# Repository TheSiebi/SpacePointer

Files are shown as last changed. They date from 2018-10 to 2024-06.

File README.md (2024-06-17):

# Space Pointer
 

A device using a Raspberry Pi and an Arduino Uno which can point at the position of the sun, moon, planets and galaxies.
Users can choose whether they want to visualize the current position, a specific timestamp or a simulation of the trajectory. Parts are self-designed and 3D-printed.

## Setup
 
 

Required parts:
- 1x Raspberry Pi (I used 3B)
- 1x Arduino (I used Uno Rev 3)
- 2x NEMA 17 Steppers
- 1x LCD (+ Keypad)
- 1x Laser 303 (or any other Laser, just modify Laser_Bracket.stl)
- 1x GPS Module
- 1x Slip Ring (I used Adafruit 22mm 12 cables)
- 2x Bearings Outer 16mm Inner 5mm

and some screws, batteries and cables.

## Demo
YouTube Demo (https://www.youtube.com/watch?v=DYivI0u8cRY)

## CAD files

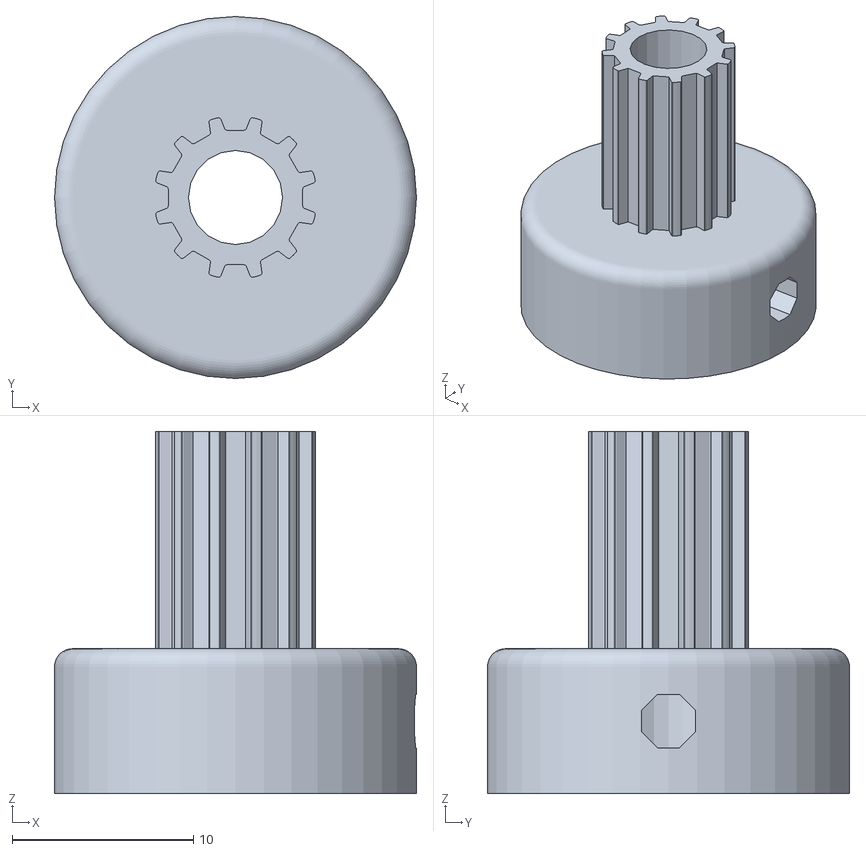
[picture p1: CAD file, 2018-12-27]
3d-parts/Pulley_12.stl
20.0 x 20.0 x 20.0

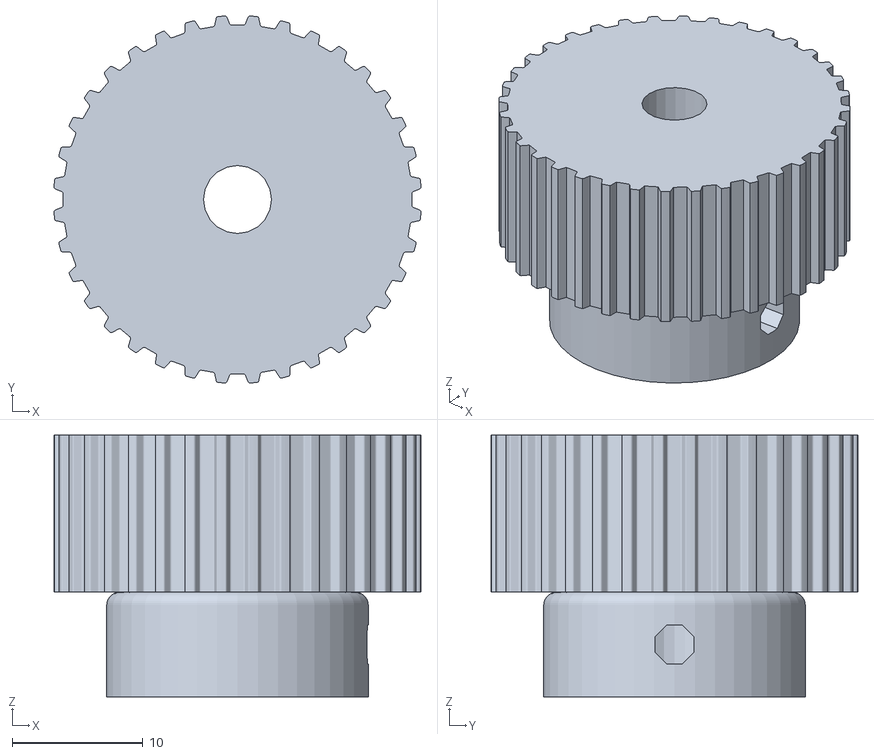
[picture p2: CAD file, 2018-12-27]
3d-parts/Pulley_36.stl
28.1 x 28.1 x 20.0

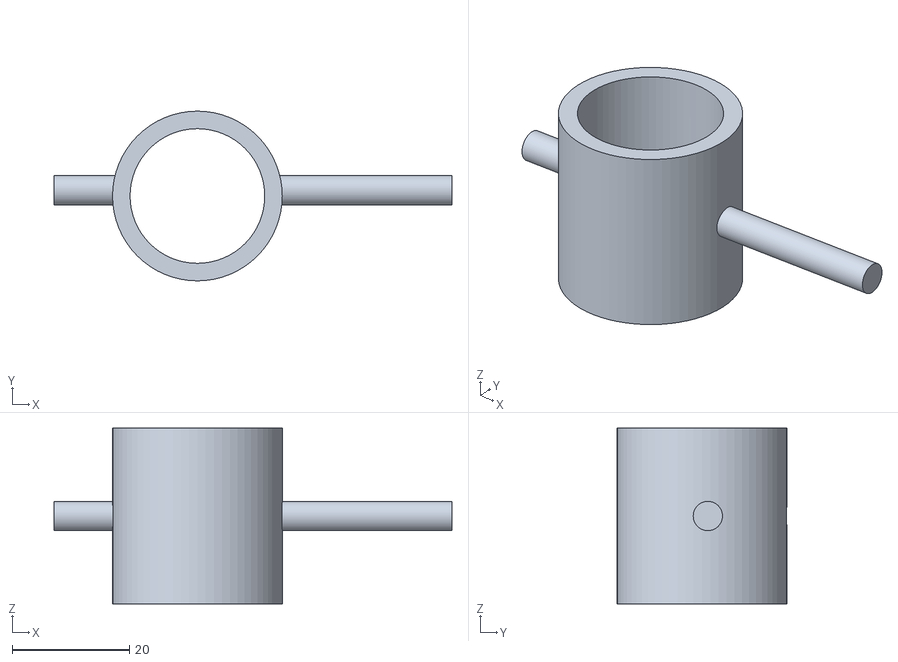
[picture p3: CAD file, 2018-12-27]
3d-parts/Laser_Bracket.stl
68.0 x 29.0 x 30.0

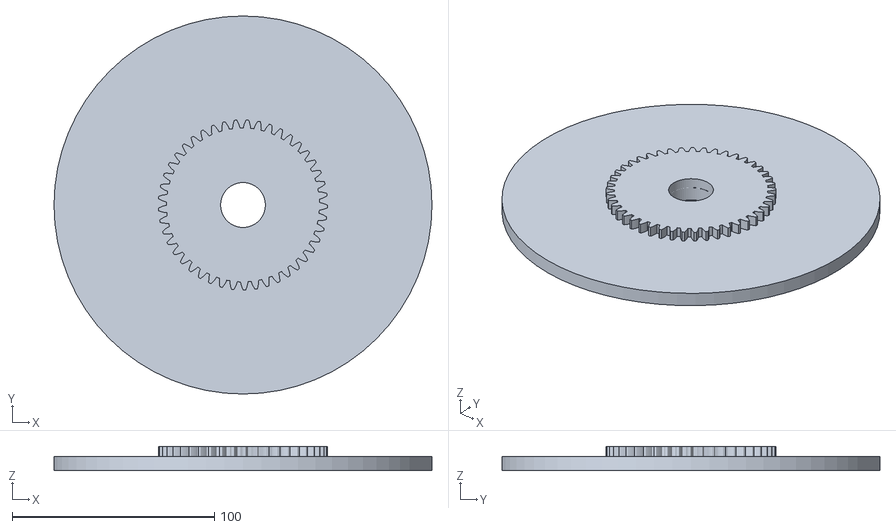
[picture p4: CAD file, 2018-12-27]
3d-parts/Lid.stl
187.0 x 187.0 x 12.1

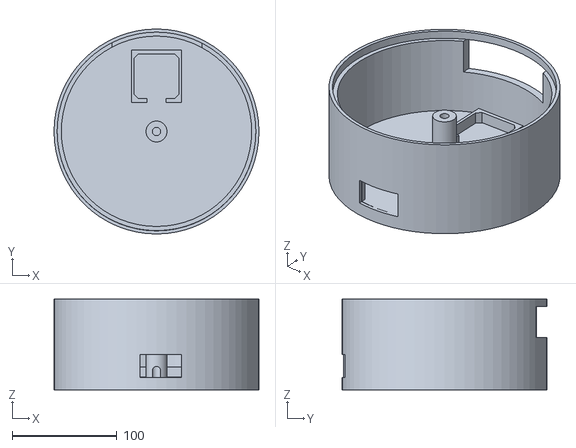
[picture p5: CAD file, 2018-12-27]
3d-parts/Casing.stl
196.0 x 196.0 x 87.0

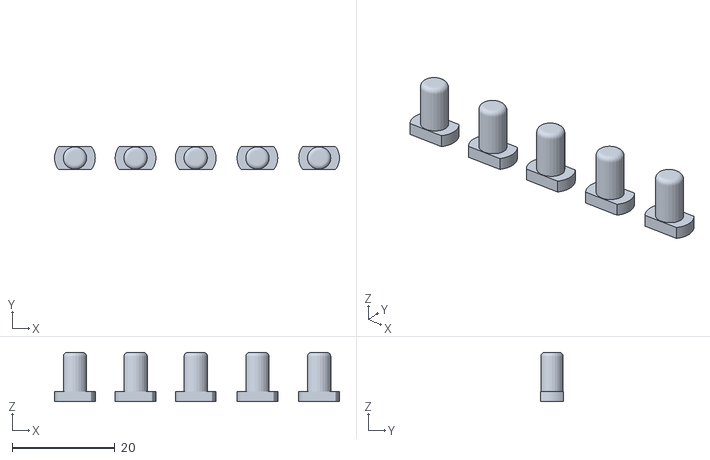
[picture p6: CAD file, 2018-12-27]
3d-parts/Buttons.stl
55.5 x 4.55 x 9.60

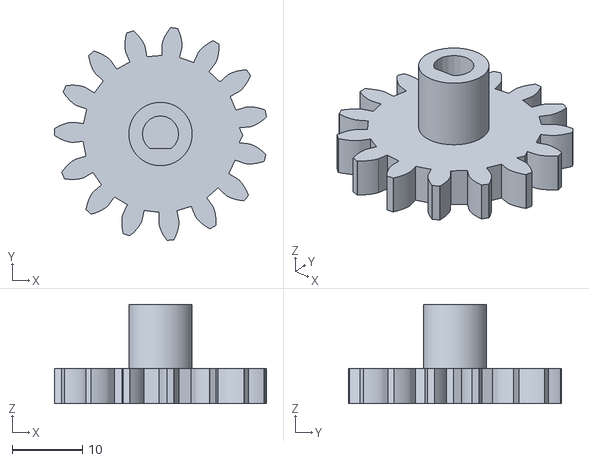
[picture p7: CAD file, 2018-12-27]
3d-parts/BottomGear.stl
30.1 x 30.2 x 14.1

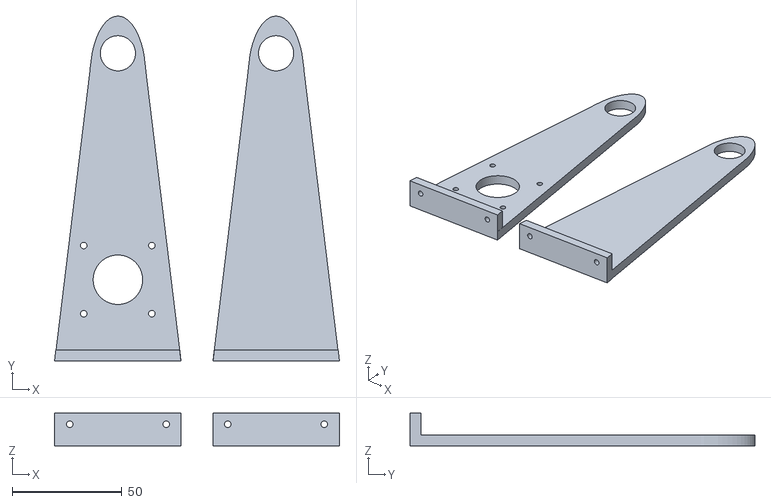
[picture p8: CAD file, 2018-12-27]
3d-parts/Top_Brackets.stl
129.7 x 156.9 x 15.0

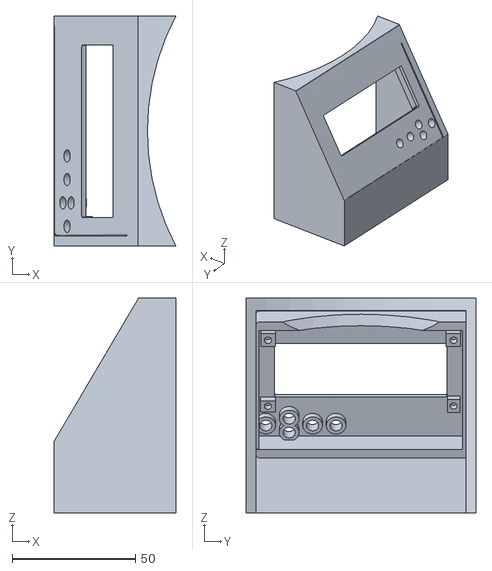
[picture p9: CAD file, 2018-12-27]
3d-parts/Display_Casing.stl
49.4 x 93.2 x 87.0

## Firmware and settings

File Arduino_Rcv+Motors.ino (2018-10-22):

/* ----------------------------------------------------------------------------
This script receives and parses positional values sent by a Raspberry Pi and
continously matches the position of two stepper motors with said values.

Author:   Michael Siebenmann
Date :    08.09.2018

History:
Version   Date        Who     Changes
1.0       08.09.2018  M7ma    created

Copyright © Michael Siebenmann, Matzingen, Switzerland. All rights reserved
-----------------------------------------------------------------------------*/

#include <Wire.h>
#include <Adafruit_MotorShield.h>

// Create the motor shield object with the default I2C address
Adafruit_MotorShield AFMS = Adafruit_MotorShield();
// Or, create it with a different I2C address (say for stacking)
// Adafruit_MotorShield AFMS = Adafruit_MotorShield(0x61);

// Connect two stepper motors with 200 steps per revolution (1.8 degree) to the two ports
Adafruit_StepperMotor *altMotor = AFMS.getStepper(200, 2);
Adafruit_StepperMotor *azMotor = AFMS.getStepper(200, 1);

const byte numChars = 32;
char receivedChars[numChars];
char tempchars[numChars];        // temporary array for use when parsing

// variables to hold the parsed data
char messageFromRPi[numChars] = {0};
float altFromRPi = 0.0;
float azFromRPi = 0.0;

boolean newData = false;

// variables for stepper positions
float altStepper = 0.0;
float azStepper = 0.0;

void setup() {
  Serial.begin(9600);
  Serial.println("Dieses Skript erwartet 3 Inputs: einen Text (String) und zwei Gleitkommazahlen");
  Serial.println("Sendeschema: <Mars, 18.9 , 24.7>  ");
  Serial.println();
  AFMS.begin();             // create with the default frequency 1.6KHz
  //AFMS.begin(1000);       // OR with a different frequency, say 1KHz
  altMotor->setSpeed(25);   // 25 rpm
  azMotor->setSpeed(25);    // 25 rpm
}

void loop() {
  recvWithStartEndMarkers();
  if (newData == true) {
    strcpy(tempchars, receivedChars);
    // this temporary copy is necessary to protect the original data
    //   because strtok() used in parseData() replaces the commas with \0
    parseData();
    showParsedData();
    newData = false;
    float altDiff = altFromRPi - altStepper;
    float azDiff  = azFromRPi  - azStepper;

    int altSteps = getMinimumSteps(altFromRPi, altStepper);
    int azSteps  = getMinimumSteps(azFromRPi, azStepper);

    Serial.print("AltSteps: ");
    Serial.println(altSteps);

    Serial.print("AzSteps: ");
    Serial.println(azSteps);
    
    if (altSteps >= 1) {
      altMotor->step(altSteps, FORWARD, MICROSTEP);
      altStepper += altSteps * 0.6;
    }

    else if (altSteps <= -1) {
      altMotor->step(abs(altSteps), BACKWARD, MICROSTEP);
      altStepper += altSteps * 0.6;
    }

    if (azSteps >= 1) {
      azMotor->step(azSteps, FORWARD, MICROSTEP);
      azStepper += azSteps * 0.6;
    }

    else if (azSteps <= -1) {
      azMotor->step(abs(azSteps), BACKWARD, MICROSTEP);
      azStepper += azSteps * 0.6;
    }
    Serial.print("AltStepper: ");
    Serial.println(altStepper);

    Serial.print("AzStepper: ");
    Serial.println(azStepper);
  }
}

void recvWithStartEndMarkers() {
  static boolean recvInProgress = false;
  static byte ndx = 0;
  char startMarker = '<';
  char endMarker = '>';
  char rc;

  while (Serial.available() > 0 && newData == false) {
    rc = Serial.read();

    if (recvInProgress == true) {
      if (rc != endMarker) {
        receivedChars[ndx] = rc;
        ndx++;
        if (ndx >= numChars) {
          ndx = numChars - 1;
        }
      }
      else {
        receivedChars[ndx] = '\0';              // terminate the string
        recvInProgress = false;
        ndx = 0;
        newData = true;
      }
    }

    else if (rc == startMarker) {
      recvInProgress = true;
    }
  }
}

void parseData() {                              // split the data into its parts
  char * strtokIndx;                            // this is used by strtok() as an index

  strtokIndx = strtok(tempchars, ",");          // get the first part - the string
  strcpy(messageFromRPi, strtokIndx);           // copy it to messageFromRPi

  strtokIndx = strtok(NULL, ",");               // this continues where the previous call left off
  altFromRPi = atof(strtokIndx);                // convert this part to a float
  altFromRPi += 90.0;

  strtokIndx = strtok(NULL, ",");
  azFromRPi = atof(strtokIndx);                 // convert this part to a float

}

void showParsedData() {
  Serial.print("Planet: ");
  Serial.println(messageFromRPi);
  Serial.print("Altitude: ");
  Serial.println(altFromRPi);
  Serial.print("Azimuth: ");
  Serial.println(azFromRPi);
}

int getMinimumSteps(float FromRPi, float Pos) { // Function to optimize the amount of steps to be time efficient and as accurat as possible
  float a = FromRPi - Pos;
  if (a > 180) {
    a = -(360 - a);
  } else if (a < -180) {
    a = 360 + a;
  }

  int b = round(a / 0.6);
  return b;
}

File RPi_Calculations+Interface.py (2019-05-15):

# -----------------------------------------------------------------------------
# This script detects the position of the user via GPS and can output
# topocentric coordinates of a desired celestial object. To interface with
# the user an Adafruit LCD with Keypad is used. Calculated coordinates
# are sent through serial communication to an Arduino Uno.
#
# Author:   Michael Siebenmann
# Date :    30.07.2018
#
# History:
# Version   Date        Who     Changes
# 1.0       30.07.2018  M7ma    created
# 1.1       14.08.2018  M7ma    complete overhaul, better usability
# 1.2       29.08.2018  M7ma    added Display Interface
# 1.3       08.09.2018  M7ma    added serial communication
# 1.4       19.09.2018  M7ma    added GPS
# 1.5       20.09.2018  M7ma    added orbit visualization, menu redesign
# 2.0       12.10.2018  M7ma    new user interface, added stars and galaxies
# 2.1       11.05.2019  M7ma    more precision thanks to AstroPy
#
# Copyright © Michael Siebenmann, Matzingen, Switzerland. All rights reserved
# -----------------------------------------------------------------------------

# -----------------------------------------------------------------------------
# Imports
# -----------------------------------------------------------------------------

import os
import time
import Adafruit_CharLCD as LCD
import datetime, math
import serial
import gpsd
from pytz import timezone
from time import sleep

from astropy.coordinates import EarthLocation, SkyCoord
from astropy.time import Time
from astropy import units as u
from astropy.coordinates import AltAz

# -----------------------------------------------------------------------------
# Setup
# -----------------------------------------------------------------------------

os.system("sudo gpsd /dev/ttyS0 -F /var/run/gpsd.sock")

date_format = "%d.%m.%Y"
time_format = "%H:%M"
dayepoch    = datetime.datetime.strptime('01.01.2000', date_format)
timeepoch   = datetime.datetime.strptime('00:00', time_format)
timeepoch   = timeepoch.replace(tzinfo = timezone('UTC'))

ser = serial.Serial('/dev/ttyACM0', 9600)

# Coordinates of Frauenfeld, in case the GPS receives no signal:
local_lon = 8.89888888
local_lat = math.radians(47.5577777)

modes = ("Echtzeit", "Custom", "Bahnsimulation")
categories = ("Sonnensystem", "Sterne", "Galaxien")
objects = {
    "Sonnensystem": ("Sonne", "Mond", "Merkur", "Venus", "Mars", "Jupiter", "Saturn", "Uranus", "Neptun"),
    "Sterne": ("Sirius", "Alpha Centauri A", "Arcturus", "Vega", "Aldebaran", "Capella", "Regulus", "Altair", "Rigel"),
    "Galaxien": ("Andromeda", "Gr. Magel. Wolke", "Kl. Magel. Wolke", "Dreiecksnebel", "Bodes Galaxie", "Centaurus A", "Zigarrengalaxie", "Sombrerogalaxie", "Virgo A")
}

solar_system = ("Sonne", "Mond", "Merkur", "Venus", "Mars", "Jupiter", "Saturn", "Uranus", "Neptun")
star_list = ("Sirius", "Alpha Centauri A", "Arcturus", "Vega", "Aldebaran", "Capella", "Regulus", "Altair", "Rigel")
galaxy_list = ("Andromeda", "Gr. Magel. Wolke", "Kl. Magel. Wolke", "Dreiecksnebel", "Bodes Galaxie", "Centaurus A", "Zigarrengalaxie", "Sombrerogalaxie", "Virgo A")

lcd = LCD.Adafruit_CharLCDPlate() # Initialize the LCD using the pins
lcd.clear()

# -----------------------------------------------------------------------------
# Functions
# -----------------------------------------------------------------------------

def shutdown():
    lcd.clear()
    lcd.set_backlight(0)
    os.system("sudo poweroff") # Shutdown the RPi

# Get user's desired mode

def get_mode():
    i = 0
    lcd.clear()
    lcd.set_cursor(0,0) # Column 0 Row 0
    lcd.message('Modus:')
    lcd.set_cursor(0,1)
    lcd.message(modes[i])
    
    while True:
        # Loop through buttons and check if pressed
        if lcd.is_pressed(LCD.LEFT):
            i -= 1
            i %= 3
            lcd.clear()
            lcd.message('Modus:')
            lcd.set_cursor(0,1)
            lcd.message(modes[i])
            time.sleep(0.3)
        elif lcd.is_pressed(LCD.RIGHT):
            i += 1
            i %= 3
            lcd.clear()
            lcd.message('Modus:')
            lcd.set_cursor(0,1)
            lcd.message(modes[i])
            time.sleep(0.3)
        elif lcd.is_pressed(LCD.SELECT):
            sleep(1)
            lcd.clear()
            break
    mode = modes[i]
    return(mode)

# Get user's desired object

def get_object():
    c = 0 # variable for switching between categories
    a = 0 # Variable for switching between objects
    isUp = True
    lcd.clear()
    lcd.set_cursor(0,0) # Column 0 Row 0
    lcd.message(categories[c] + ":")
    lcd.set_cursor(0,1)
    lcd.message(objects[categories[c]][a])
    print('Press Ctrl-C to quit.')
    while True: 
        while isUp:
            if lcd.is_pressed(LCD.RIGHT):
                c += 1
                c %= 3
                lcd.clear()
                lcd.message(categories[c] + ":")
                lcd.set_cursor(0,1)
                lcd.message(objects[categories[c]][a])
                time.sleep(0.3)
            elif lcd.is_pressed(LCD.LEFT):
                c -= 1
                if (c < 0):
                    c = 2
                lcd.clear()
                lcd.message(categories[c] + ":")
                lcd.set_cursor(0,1)
                lcd.message(objects[categories[c]][a])
                time.sleep(0.3)
            elif lcd.is_pressed(LCD.SELECT):
                break
            elif lcd.is_pressed(LCD.UP) or lcd.is_pressed(LCD.DOWN):
                isUp = not isUp
                time.sleep(0.3)
        while not isUp:
            if lcd.is_pressed(LCD.RIGHT):
                a += 1
                a %= 9
                time.sleep(0.3)
                lcd.clear()
                lcd.message(categories[c] + ":")
                lcd.set_cursor(0,1)
                lcd.message(objects[categories[c]][a])
            elif lcd.is_pressed(LCD.LEFT):
                a -= 1
                if (a < 0):
                    a = 8
                lcd.clear()
                lcd.message(categories[c] + ":")
                lcd.set_cursor(0,1)
                lcd.message(objects[categories[c]][a])
                time.sleep(0.3)
            elif lcd.is_pressed(LCD.SELECT):
                break
            elif lcd.is_pressed(LCD.UP) or lcd.is_pressed(LCD.DOWN):
                isUp = not isUp
                time.sleep(0.3)
                print(repr(isUp))
        if lcd.is_pressed(LCD.SELECT):
            break
    time.sleep(1)
    return(objects[categories[c]][a])

# Calculate altitude and azimuth of the chosen object
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
